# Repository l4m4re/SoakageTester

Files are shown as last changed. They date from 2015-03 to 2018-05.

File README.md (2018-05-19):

# SoakageTester
Hard and software for studying dielectric absorption aka "soakage" in electrolytic capacitors and/or batteries

# Intro

This is a capacitor/battery pulsed charge-discharge cycle tester, as part of a
project to investigate the theory that the well known "capacitor soakage" or
"battery action" effect observed with electrolytic capacitors can be enhanced
using pulsed charging, as demonstrated by John Bedini et al for years. For
more information on the theory, see my article about [The Cole-Hackenberger
(Gray) Power
Supply](http://www.tuks.nl/wiki/index.php/Main/ColeHackenbergerPowerSupply).

# Hardware

The hardware consists of:

1) An adjustable power supply, 0-300V;
2) Pulse charge circuitry, steered by a BeagleBone, using a MOSFET;
3) Current measurement circuitry, using a shunt, some opamps to amplify
the input signal, implement a low pass filter, etc.
4) Voltage measurement circuitry.

Both the current en voltage measurements are done by the BeagleBone using
it's analog inputs and it's ADC. 

Based on [small-scope](https://hackaday.io/project/5881-small-scope) by Marvin Sinister.

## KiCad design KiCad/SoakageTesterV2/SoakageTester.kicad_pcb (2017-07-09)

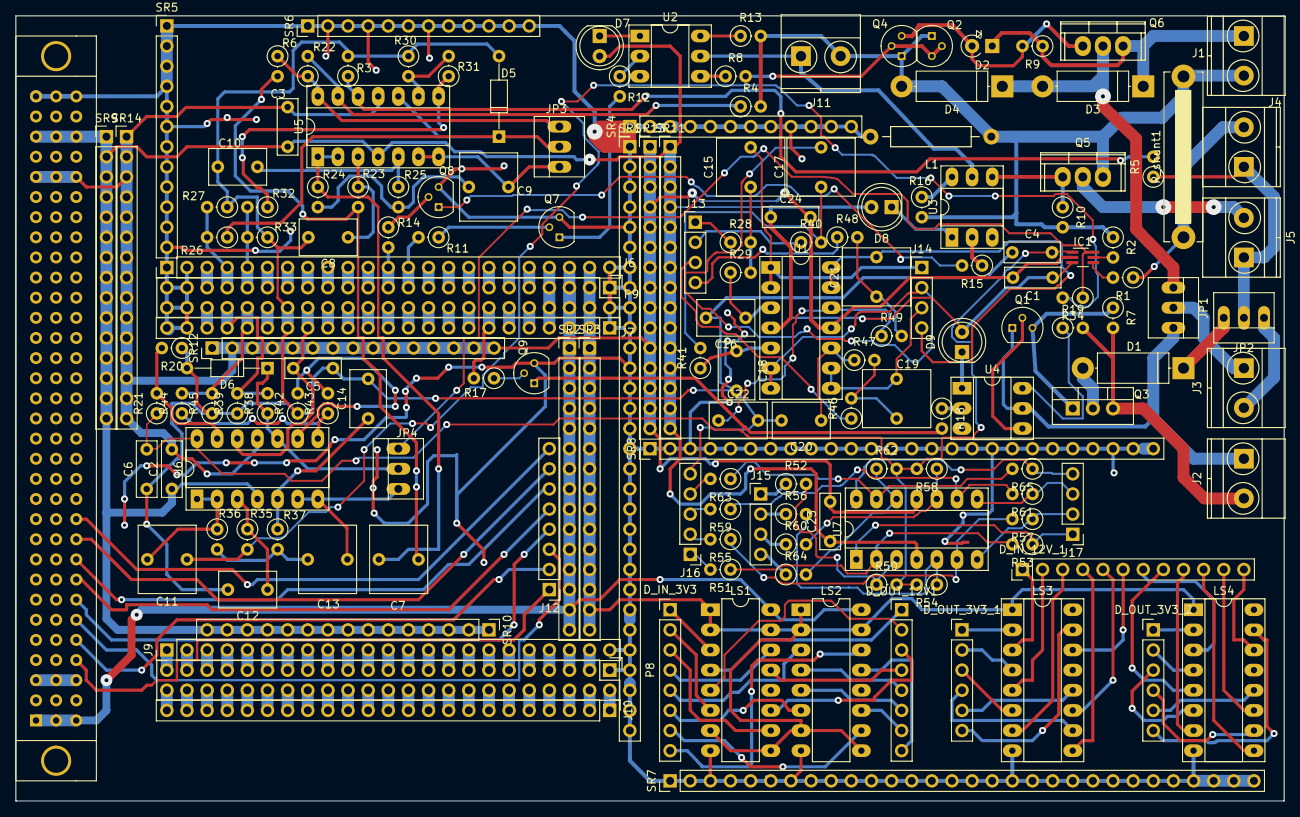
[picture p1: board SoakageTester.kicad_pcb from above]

Board: 2 copper layers, 160.0 x 99.1 mm, 163 parts (0 on the bottom side), 230 nets.

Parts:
C1, C2, C3, C4, C5, C6, C23, C24: 100n; C_Rect_L7.0mm_W2.5mm_P5.00mm
C7, C9, C11, C13, C15, C17, C19, C21: 10n; C_Rect_L7.2mm_W8.5mm_P5.00mm_FKP2_FKP2_MKS2_MKP2
C8, C10, C12, C14, C16, C18, C20, C22: 1n; C_Rect_L7.2mm_W4.5mm_P5.00mm_FKS2_FKP2_MKS2_MKP2
D1, D3, D4: 1N4007; D_5W_P12.70mm_Horizontal
D2: 12V; D_A-405_P2.54mm_Vertical_KathodeUp
D5, D6: 1n4148; D_DO-35_SOD27_P10.16mm_Horizontal
D7, D8, D9: LED; LED_D5.0mm
D_IN_3V3: CONN_01X08; Pin_Header_Straight_1x08_Pitch2.54mm
D_IN_12V_1: CONN_01X12; Pin_Header_Straight_1x12_Pitch2.54mm
D_OUT_3V3_1, D_OUT_3V3_2: CONN_01X06; Pin_Header_Straight_1x06_Pitch2.54mm
D_OUT_12V1: CONN_01X08; Pin_Header_Straight_1x08_Pitch2.54mm
IC1: ina213; SOT-363_SC-70-6_Handsoldering
J1: 30-300V; TerminalBlock_Pheonix_MKDS1.5-2pol
J2: 12V_Bedini; TerminalBlock_Pheonix_MKDS1.5-2pol
J3: Coil; TerminalBlock_Pheonix_MKDS1.5-2pol
J4: Test Cap; TerminalBlock_Pheonix_MKDS1.5-2pol
J5: Load; TerminalBlock_Pheonix_MKDS1.5-2pol
J6, J7, J9, J10: CONN_01X23; Pin_Header_Straight_1x23_Pitch2.54mm
J8: C96ABC; C96ABCMD
J11: 12V Opto; TerminalBlock_Pheonix_MKDS1.5-2pol
J12: CONN_01X08; Pin_Header_Straight_1x08_Pitch2.54mm
J13, J14, J15, J17: CONN_01X04; Pin_Header_Straight_1x04_Pitch2.54mm
J16: CONN_01X05; Pin_Header_Straight_1x05_Pitch2.54mm
JP1, JP2, JP3, JP4: Jumper_NC_Dual; PINHEAD1-3
L1: 10m; Choke_Horizontal_RM15mm
LS1, LS2: CD40109BPW_SOP65P640X120-16N; DIP-16_W7.62mm_LongPads
LS3, LS4: CD74HC4050E_DIP254P762X508-16; DIP-16_W7.62mm_Socket_LongPads
P8, P9: BeagleBone_Black_Header; Socket_BeagleBone_Black
Q1, Q7, Q8, Q9: BC337-40; TO-92_Molded_Narrow
Q2, Q4: MPSA42; TO-92_Molded_Narrow
Q3: BUX85; TO-220_Vertical
Q5: IRFB3307; TO-220
Q6: IXTP10P50P; TO-220
R1, R2: 180k; R_Axial_DIN0207_L6.3mm_D2.5mm_P2.54mm_Vertical
R3, R6, R10, R20: 10k; R_Axial_DIN0207_L6.3mm_D2.5mm_P2.54mm_Vertical
R4, R5, R13, R16, R19, R31, R43: 1M; R_Axial_DIN0207_L6.3mm_D2.5mm_P2.54mm_Vertical
R7, R12, R15, R18, R27, R33, R39, R45: 1k; R_Axial_DIN0207_L6.3mm_D2.5mm_P2.54mm_Vertical
R8: 680; R_Axial_DIN0207_L6.3mm_D2.5mm_P2.54mm_Vertical
R9: 22k; R_Axial_DIN0207_L6.3mm_D2.5mm_P2.54mm_Vertical
R11, R14, R17: 3k3; R_Axial_DIN0207_L6.3mm_D2.5mm_P2.54mm_Vertical
R21: 20k; R_Axial_DIN0207_L6.3mm_D2.5mm_P2.54mm_Vertical
R22, R28, R34, R40, R46, R48: 453; R_Axial_DIN0207_L6.3mm_D2.5mm_P2.54mm_Vertical
R23, R35: 1k78; R_Axial_DIN0207_L6.3mm_D2.5mm_P2.54mm_Vertical
R24, R36: 243; R_Axial_DIN0207_L6.3mm_D2.5mm_P2.54mm_Vertical
R25, R37: 4k32; R_Axial_DIN0207_L6.3mm_D2.5mm_P2.54mm_Vertical
R26, R32, R38, R44: 4k99; R_Axial_DIN0207_L6.3mm_D2.5mm_P2.54mm_Vertical
R29, R41, R47, R49: 1234; R_Axial_DIN0207_L6.3mm_D2.5mm_P2.54mm_Vertical
R30, R42: 40k; R_Axial_DIN0207_L6.3mm_D2.5mm_P2.54mm_Vertical
R50, R51, R52, R53, R54, R55, R56, R57, R58, R59, R60, R61, R62, R63, R64, R65: 3456; R_Axial_DIN0207_L6.3mm_D2.5mm_P2.54mm_Vertical
R_shunt1: 10m; R_Bare_Metal_Element_L21.3mm_W4.8mm_P20.30mm
SR1, SR7: CONN_01X30; Pin_Header_Straight_1x30_Pitch2.54mm
SR2, SR3, SR9, SR10, SR11, SR12, SR13, SR14: CONN_01X15; Pin_Header_Straight_1x15_Pitch2.54mm
SR4, SR5, SR6: CONN_01X12; Pin_Header_Straight_1x12_Pitch2.54mm
SR8: CONN_01X26; Pin_Header_Straight_1x26_Pitch2.54mm
U1, U5, U6, U7: LM2902N; DIP-14_W7.62mm_Socket_LongPads
U2, U3, U4: 4N25; DIP-6_W7.62mm_Socket_LongPads

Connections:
+3V3: J6.22, J7.2, LS1.1, LS1.2, LS1.7, LS1.9, LS1.15, LS2.1, LS2.2, LS2.7, LS2.9, LS2.15, LS3.1, LS4.1, P9.3, P9.4, SR3.1, SR3.2, SR3.3, SR3.4, SR3.5, SR3.6, SR3.7, SR3.8, SR3.9, SR3.10, SR3.11, SR3.12, SR3.13, SR3.14, SR3.15
+5V: J6.21, J7.3, J8.A1, J8.B1, J8.C1, LS1.16, LS2.16, P9.5, P9.6, SR2.1, SR2.2, SR2.3, SR2.4, SR2.5, SR2.6, SR2.7, SR2.8, SR2.9, SR2.10, SR2.11, SR2.12, SR2.13, SR2.14, SR2.15
+12VA: J11.1, U2.5, U3.5
-5V: J8.A3, J8.B3, J8.C3
/Analog Experimental/Amp1/V_in+: J15.1, R52.1
/Analog Experimental/Amp1/V_in-: J16.1, R51.2
/Analog Experimental/Amp1/V_out: J17.1, R53.1, U7.1
/Analog Experimental/Amp2/V_in+: J15.2, R56.1
/Analog Experimental/Amp2/V_in-: J16.2, R55.2
/Analog Experimental/Amp2/V_out: J17.2, R57.1, U7.7
/Analog Experimental/Amp3/V_in+: J15.3, R60.1
/Analog Experimental/Amp3/V_in-: J16.3, R59.2
/Analog Experimental/Amp3/V_out: J17.3, R61.1, U7.8
/Analog Experimental/Amp4/V_in+: J15.4, R64.1
/Analog Experimental/Amp4/V_in-: J16.4, R63.2
/Analog Experimental/Amp4/V_out: J17.4, R65.1, U7.14
/Analog Experimental/Filter1/V_in: J13.1, R28.1
/Analog Experimental/Filter1/V_out: C15.2, J14.1, U1.1, U1.2
/Analog Experimental/Filter2/V_in: J13.2, R40.1
/Analog Experimental/Filter2/V_out: C17.2, J14.2, U1.6, U1.7
/Analog Experimental/Filter3/V_in: J13.3, R46.1
/Analog Experimental/Filter3/V_out: C19.2, J14.3, U1.8, U1.9
/Analog Experimental/Filter4/V_in: J13.4, R48.1
/Analog Experimental/Filter4/V_out: C21.2, J14.4, U1.13, U1.14
/Analog Experimental/V_ref: C4.2, C6.2, IC1.1, R21.1, R50.2, R54.2, R58.2, R62.2, U6.14
/Beagle/AIN0: J6.4, P9.39, R26.2, R27.2
/Beagle/AIN1: J7.20, P9.40, R38.2, R39.2
/Beagle/AIN2: J6.5, P9.37, R32.2, R33.2
/Beagle/AIN3: J7.19, P9.38, R44.2, R45.2
/Beagle/AIN4: J6.7, P9.33
/Beagle/AIN5: J7.18, P9.36
/Beagle/AIN6: J6.6, P9.35
/Beagle/Bedini: J7.7, P9.14, R17.2
/Beagle/C4: J8.C4, J12.1
/Beagle/C5: J8.C5, J12.2
/Beagle/C6: J8.C6, J12.3
/Beagle/C7: J8.C7, J12.4
/Beagle/C8: J8.C8, J12.5
/Beagle/C9: J8.C9, J12.6
/Beagle/C10: J8.C10, J12.7
/Beagle/C11: J8.C11, J12.8
/Beagle/Charge: J6.13, P9.21, R11.2
/Beagle/Discharge: J6.12, P9.23, R14.2
/Beagle/GPIO_7: J7.21, P9.42
/Beagle/GPIO_20: J6.3, P9.41
/Beagle/PWR_BUT: J6.19, P9.9
/Beagle/SYS_RESETN: J7.5, P9.10
/Input Amplifier/IC1_IN_NEG: IC1.5, R2.2
/Input Amplifier/IC1_IN_POS: IC1.4, R1.2
/Input Amplifier/I_sense: J4.2, R1.1, R_shunt1.1
/Input Amplifier/Is_x_5: IC1.6, JP4.3, R34.1
/Input Amplifier/V_cap: J4.1, J5.1, JP2.2, R5.1
/Input Amplifier/V_cap_div_100: JP3.3, R6.1, R22.1, U5.14
/Power Electronics/+300V_PWR: D2.1, D3.1, J1.1, Q6.3, R9.1
/Power Electronics/Bedini+12V: J2.1, JP1.3, Q1.1, U4.5
/Power Electronics/BediniOpto/OUT_Emitter: Q1.2, U4.4
/Power Electronics/Bedini_GND: J2.2, Q3.3, R7.2, R19.2
/Power Electronics/ChargeOpto/OUT_Emitter: R8.1, U2.4
/Power Electronics/DischargeOpto/OUT_Emitter: Q5.1, R10.1, U3.4
/experimental/1A1: D_IN_12V_1.1, LS3.3
/experimental/1A2: D_IN_12V_1.2, LS3.5
/experimental/1A3: D_IN_12V_1.3, LS3.7
/experimental/1A4: D_IN_12V_1.4, LS3.9
/experimental/1A5: D_IN_12V_1.5, LS3.11
/experimental/1A6: D_IN_12V_1.6, LS3.14
/experimental/2A1: D_IN_12V_1.7, LS4.3
/experimental/2A2: D_IN_12V_1.8, LS4.5
/experimental/2A3: D_IN_12V_1.9, LS4.7
/experimental/2A4: D_IN_12V_1.10, LS4.9
/experimental/2A5: D_IN_12V_1.11, LS4.11
/experimental/2A6: D_IN_12V_1.12, LS4.14
/experimental/A1: D_IN_3V3.1, LS1.3
/experimental/A2: D_IN_3V3.5, LS2.3
/experimental/B1: D_IN_3V3.2, LS1.6
/experimental/B2: D_IN_3V3.6, LS2.6
/experimental/C1: D_IN_3V3.3, LS1.10
/experimental/C2: D_IN_3V3.7, LS2.10
/experimental/D1: D_IN_3V3.4, LS1.14
/experimental/D2: D_IN_3V3.8, LS2.14
/experimental/E1: D_OUT_12V1.1, LS1.4
/experimental/E2: D_OUT_12V1.5, LS2.4
/experimental/F1: D_OUT_12V1.2, LS1.5
/experimental/F2: D_OUT_12V1.6, LS2.5
/experimental/G1: D_OUT_12V1.3, LS1.11
/experimental/G2: D_OUT_12V1.7, LS2.11
/experimental/H1: D_OUT_12V1.4, LS1.13
/experimental/H2: D_OUT_12V1.8, LS2.13
GNDA_ADC: C4.1, C5.1, C6.1, C8.2, C10.2, C12.2, C14.2, C16.2, C18.2, C20.2, C22.2, D5.2, D6.2, J7.17, J16.5, P9.34, R3.2, R20.1, R27.1, R30.1, R33.1, R39.1, R42.1, R45.1
GNDD: J6.1, J6.2, J6.23, J7.1, J7.22, J7.23, J8.A32, J8.B32, J8.C32, J9.23, L1.2, LS1.8, LS2.8, LS3.8, LS4.8, P8.1, P9.1, P9.2, P9.43, P9.44, P9.45, P9.46, Q7.3, Q8.3, Q9.3, SR1.1, SR1.2, SR1.3, SR1.4, SR1.5, SR1.6, SR1.7, SR1.8, SR1.9, SR1.10, SR1.11, SR1.12, SR1.13, SR1.14, SR1.15, SR1.16, SR1.17, SR1.18, SR1.19, SR1.20, SR1.21, SR1.22, SR1.23, SR1.24, SR1.25, SR1.26, SR1.27, SR1.28, SR1.29, SR1.30, SR4.1, SR4.2, SR4.3, SR4.4, SR4.5, SR4.6, SR4.7, SR4.8, SR4.9, SR4.10, SR4.11, SR4.12, SR5.1, SR5.2, SR5.3, SR5.4, SR5.5, SR5.6, SR5.7, SR5.8, SR5.9, SR5.10, SR5.11, SR5.12, SR6.1, SR6.2, SR6.3, SR6.4, SR6.5, SR6.6, SR6.7, SR6.8, SR6.9, SR6.10, SR6.11, SR6.12, SR7.1, SR7.2, SR7.3, SR7.4, SR7.5, SR7.6, SR7.7, SR7.8, SR7.9, SR7.10, SR7.11, SR7.12, SR7.13, SR7.14, SR7.15, SR7.16, SR7.17, SR7.18, SR7.19, SR7.20, SR7.21, SR7.22, SR7.23, SR7.24, SR7.25, SR7.26, SR7.27, SR7.28, SR7.29, SR7.30, SR8.1, SR8.2, SR8.3, SR8.4, SR8.5, SR8.6, SR8.7, SR8.8, SR8.9, SR8.10, SR8.11, SR8.12, SR8.13, SR8.14, SR8.15, SR8.16, SR8.17, SR8.18, SR8.19, SR8.20, SR8.21, SR8.22, SR8.23, SR8.24, SR8.25, SR8.26
GNDPWR: D4.2, J1.2, J11.2, L1.1, Q2.1, Q4.1, Q5.3, R2.1, R4.2, R10.2, R13.2, R16.2, R_shunt1.2
unnamed: C7.1, R22.2, R23.2
unnamed: C7.2, R24.1, U5.1, U5.2
unnamed: C8.1, R23.1, U5.3
unnamed: C9.1, R24.2, R25.2
unnamed: C9.2, JP3.1, U5.6, U5.7
unnamed: C10.1, R25.1, U5.5
unnamed: C11.1, R34.2, R35.2
unnamed: C11.2, R36.1, U6.1, U6.2
unnamed: C12.1, R35.1, U6.3
unnamed: C13.1, R36.2, R37.2
unnamed: C13.2, JP4.1, U6.6, U6.7
unnamed: C14.1, R37.1, U6.5
unnamed: C15.1, R28.2, R29.2
unnamed: C16.1, R29.1, U1.3
unnamed: C17.1, R40.2, R41.2
unnamed: C18.1, R41.1, U1.5
unnamed: C19.1, R46.2, R47.2
unnamed: C20.1, R47.1, U1.10
unnamed: C21.1, R48.2, R49.2
unnamed: C22.1, R49.1, U1.12
unnamed: D1.1, JP2.3
unnamed: D1.2, Q3.2
unnamed: D2.2, Q4.3, Q6.1, R9.2
unnamed: D3.2, D4.1, JP1.1, Q6.2
unnamed: D5.1, JP3.2, R26.1, U5.10
unnamed: D6.1, JP4.2, R38.1, U6.10
unnamed: D7.1, U2.1
unnamed: D8.1, U3.1
unnamed: D9.1, U4.1
unnamed: D_OUT_3V3_1.1, LS3.2
unnamed: D_OUT_3V3_1.2, LS3.4
unnamed: D_OUT_3V3_1.3, LS3.6
unnamed: D_OUT_3V3_1.4, LS3.10
unnamed: D_OUT_3V3_1.5, LS3.12
unnamed: D_OUT_3V3_1.6, LS3.15
unnamed: D_OUT_3V3_2.1, LS4.2
unnamed: D_OUT_3V3_2.2, LS4.4
unnamed: D_OUT_3V3_2.3, LS4.6
unnamed: D_OUT_3V3_2.4, LS4.10
unnamed: D_OUT_3V3_2.5, LS4.12
unnamed: D_OUT_3V3_2.6, LS4.15
unnamed: J3.1, JP1.2
unnamed: J3.2, JP2.1
unnamed: J5.2, Q5.2
unnamed: J6.8, P9.31
unnamed: J6.9, P9.29
unnamed: J6.10, P9.27
unnamed: J6.11, P9.25
unnamed: J6.14, P9.19
unnamed: J6.15, P9.17
unnamed: J6.16, P9.15
unnamed: J6.17, P9.13
unnamed: J6.18, P9.11
unnamed: J7.6, P9.12
unnamed: J7.8, P9.16
unnamed: J7.9, P9.18
unnamed: J7.10, P9.20
unnamed: J7.11, P9.22
unnamed: J7.12, P9.24
unnamed: J7.13, P9.26
unnamed: J7.14, P9.28
unnamed: J7.15, P9.30
unnamed: J9.1, P8.45
unnamed: J9.2, P8.43
unnamed: J9.3, P8.41
unnamed: J9.4, P8.39
unnamed: J9.5, P8.37
unnamed: J9.6, P8.35
unnamed: J9.7, P8.33
unnamed: J9.8, P8.31
unnamed: J9.9, P8.29
unnamed: J9.10, P8.27
unnamed: J9.11, P8.25
unnamed: J9.12, P8.23
unnamed: J9.13, P8.21
unnamed: J9.14, P8.19
unnamed: J9.15, P8.17
unnamed: J9.16, P8.15
unnamed: J9.17, P8.13
unnamed: J9.18, P8.11
unnamed: J9.19, P8.9
unnamed: J9.20, P8.7
unnamed: J9.21, P8.5
unnamed: J9.22, P8.3
unnamed: J10.1, P8.2
unnamed: J10.2, P8.4
unnamed: J10.3, P8.6
unnamed: J10.4, P8.8
unnamed: J10.5, P8.10
unnamed: J10.6, P8.12
unnamed: J10.7, P8.14
unnamed: J10.8, P8.16
unnamed: J10.9, P8.18
unnamed: J10.10, P8.20
unnamed: J10.11, P8.22
unnamed: J10.12, P8.24
unnamed: J10.13, P8.26
unnamed: J10.14, P8.28
unnamed: J10.15, P8.30
unnamed: J10.16, P8.32
unnamed: J10.17, P8.34
unnamed: J10.18, P8.36
unnamed: J10.19, P8.38
unnamed: J10.20, P8.40
unnamed: J10.21, P8.42
unnamed: J10.22, P8.44
unnamed: J10.23, P8.46
unnamed: Q1.3, Q3.1, R7.1
unnamed: Q2.2, Q2.3, Q4.2, R8.2
unnamed: Q7.1, R12.2
unnamed: Q7.2, R11.1
unnamed: Q8.1, R15.2
unnamed: Q8.2, R14.1
unnamed: Q9.1, R18.2
unnamed: Q9.2, R17.1
unnamed: R3.1, R5.2, U5.12
unnamed: R4.1, R6.2, U5.13
unnamed: R12.1, U2.2
unnamed: R13.1, U2.6
unnamed: R15.1, U3.2
unnamed: R16.1, U3.6
unnamed: R18.1, U4.2
unnamed: R19.1, U4.6
unnamed: R20.2, R21.2, U6.13
unnamed: R30.2, R31.2, U5.9
unnamed: R31.1, R32.1, U5.8
unnamed: R42.2, R43.2, U6.9
unnamed: R43.1, R44.1, U6.8
unnamed: R50.1, R52.2, U7.3
unnamed: R51.1, R53.2, U7.2
unnamed: R54.1, R56.2, U7.5
unnamed: R55.1, R57.2, U7.6
unnamed: R58.1, R60.2, U7.10
unnamed: R59.1, R61.2, U7.9
unnamed: R62.1, R64.2, U7.12
unnamed: R63.1, R65.2, U7.13
OPAMP_Vdd: C1.2, C2.2, C3.2, C23.2, C24.2, IC1.2, J8.A28, J8.B28, J8.C28, SR12.1, SR12.2, SR12.3, SR12.4, SR12.5, SR12.6, SR12.7, SR12.8, SR12.9, SR12.10, SR12.11, SR12.12, SR12.13, SR12.14, SR12.15, SR13.1, SR13.2, SR13.3, SR13.4, SR13.5, SR13.6, SR13.7, SR13.8, SR13.9, SR13.10, SR13.11, SR13.12, SR13.13, SR13.14, SR13.15, SR14.1, SR14.2, SR14.3, SR14.4, SR14.5, SR14.6, SR14.7, SR14.8, SR14.9, SR14.10, SR14.11, SR14.12, SR14.13, SR14.14, SR14.15, U1.11, U5.11, U6.11, U7.11
OPAMP_Vss: C1.1, C2.1, C3.1, C23.1, C24.1, D7.2, D8.2, D9.2, IC1.3, J8.A30, J8.B30, J8.C30, SR9.1, SR9.2, SR9.3, SR9.4, SR9.5, SR9.6, SR9.7, SR9.8, SR9.9, SR9.10, SR9.11, SR9.12, SR9.13, SR9.14, SR9.15, SR10.1, SR10.2, SR10.3, SR10.4, SR10.5, SR10.6, SR10.7, SR10.8, SR10.9, SR10.10, SR10.11, SR10.12, SR10.13, SR10.14, SR10.15, SR11.1, SR11.2, SR11.3, SR11.4, SR11.5, SR11.6, SR11.7, SR11.8, SR11.9, SR11.10, SR11.11, SR11.12, SR11.13, SR11.14, SR11.15, U1.4, U5.4, U6.4, U7.4
SYS_5V: J6.20, J7.4, P9.7, P9.8
VDD_ADC: C5.2, J7.16, P9.32, U6.12

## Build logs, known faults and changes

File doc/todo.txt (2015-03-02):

Problems:

1) Offset current-measurement drifts. 
  - Use zener diode + 2 equal transistors
  - Continuously re-calibrate

	Measurements:
	09/05  9:55  2.52V / -0.11A 

2) Resolution too low at low currents. 
  - Change amplification of last opamp section
  - Add second opamp section for low currents and
    switch between 2 resolutions, f.e. at 4.5 A.

3) Low-pass filter may add too much error.
  - increase sampling freq & filter edge freq
  - decrease order of filter.

TODO:

1) Higher voltages with variac

2) User interface with python script

3) Nelder Mead optimizer

Simulate with 6 kHz, 50% duty and see max amp.
-> no success at 6 kHz. Max current about 40 Amps.

ORDER:

- transistors 
  - small signal NPN+PNP
  - high voltage NPN like BF393

- 2.5V zeners / 0.9V zener / ref voltage.

- SMD IC's Kimo's remote

- PCB's

- Litze / tin

- screwing connectors

- some pots, like 10-turns 

- OPAMPS
  - TL074/084
  - LM324

- Long Arduino/Beagle connectors/headers

- External ADC or Arduino Zero or Due (EUR 43) (12-bit ADC)

----------------------------------------------------------------------

Arduino Due also has 12-bit ADC.

Arduino comparison and ADC explanation and calibration:
http://www.djerickson.com/arduino/

Due:
Flash     : 512K
RAM       : 96K
ADC inputs: 16 x 12 bits, 1MHz

http://frenki.net/2013/10/fast-analogread-with-arduino-due/

"With this improvement conversion time dropped to 1.79uS."

That would be 558 kHz.

Well enough for 3 channels at 128 or 2 at 256 kHz. :)

"But then I found great piece of code from arduino forum use
"stimmer" which ignores analogRead by using more direc
approach: http://goo.gl/Bn8Z4P
With this solution single conversion takes only 1uS
And now we have a cheap 1MSa/s oscilloscope. ;)"

This is in free-running mode, though. 

That would mean: 1 MHz max, or 500 kHz for 2 channels or
333 kHz for 3 channes.
Well enough for 3 channels at 128 or 256 kHz. :)

Comments:

"To get 1 msps you need to set prescaller at 21 MHz.  Right, it's
"overclocking" , as data sheet says 20 MHz is max Check it out, there is
a code: http://coolarduino.blogspot.ca/2015_06_01_archive.html"

Available via archive.org:

http://web.archive.org/web/20150814074247/http://coolarduino.blogspot.ca/2015/07/fast-sampling-with-arduino-due.html

Further comments:

-:-

Anatoly Kuzmenko : Hi! Thanks for the tip! I've checked out the Atmel
SAM3X8E datasheet
(http://www.atmel.com/.../Atmel-11057-32-bit-Cortex-M3...). And I found
that the ADCClock=MCK/((PRESCAL+1)*2) in page 1334. Also, in page 1403,
it shows that max. ADC Clock is 22MHZ , and the Conversion
time(tCONV)=20*ADC Clock Period(tCP_ADC) . That means, theoretically,
Due's ADC sampling rate= MCK/40N, where MCK=84MHZ and N=2 to 42. The
maximum sampling rate would be 84MHZ/(40*2)=1.05MHZ ! It's better than
expected, and It's not overclocking!

Am I right?
Like · Reply · Jul 10, 2015 9:56am
Anatoly Kuzmenko ·
Centre Pauline Julien

Chi-hao Li : Wrong. I'm sure, atmel made another mistake, "typo" this
time. I have doc dated 2012, that says 20 MHz:

https://drive.google.com/.../0Bw4tXXvyWtFVdmRsLVh.../view...

Here is confirmation:

http://asf.atmel.com/docs/latest/sam3x/html/adc_8h.html

This explain, why you can't run ADC at 1 MHZ if you set : adc_init(ADC,
SystemCoreClock, ADC_FREQ_MAX, ADC_STARTUP_FAST);

It has to be:

adc_init(ADC, SystemCoreClock, 21000000UL, ADC_STARTUP_FAST);

http://coolarduino.blogspot.ca/.../fast-sampling-with...

-:-

Continue at:

https://gist.github.com/pklaus/5921022

In-circuit debugging:

http://forum.arduino.cc/index.php?topic=134907.15

"For those interested in debugging Arduino Due and saving some money, I
recommend to use an Atmel ICE that costs around $25 or a SWD CMSIS-DAP
($20) like the one from adafruit and shown in the following picture,
instead of pay over $100 for a SAM-ICE. Of course, the mentioned cheap
options have limited features but at least let you to perform debugging
functions like stepping, breakpoints, watch points, and firmware
downloads."

The Adafruit one can be ordered in the UK for about EUR 40, incl p&p:
http://www.ebay.nl/itm/Adafruit-IBDAP-CMSIS-DAP-JTAG-SWD-Debug-Adapter-Kit-ADA2764-/151984771454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

Other boards:

BeagleBone

https://www.conrad.nl/nl/seeed-studio-102010027-beaglebone-green-1389300.html

EUR 50.

EUR 36 at Mouser:
http://nl.mouser.com/ProductDetail/Seeed-Studio/102010027/?qs=Hlcjo%2fO3pQ5AxSET1oW%252b%252bg%3d%3d

BB-BBLK-000 Rev C BeagleBone Black Mini-PC Rev C (element14 editie)
EUR 65
EUR 52 at Mouser

http://www.seeedstudio.com/wiki/BeagleBone_Green#Analog_Inputs

This is a single 12-bit analog-to-digital converter with 8 channels,
7 of which are made available on the headers.  

http://beaglebone.cameon.net/home/reading-the-analog-inputs-adc

There are 7 analog inputs on the BeagleBone.

ADC properties:
 - 12 bits (Output values in the range 0-4095)
 - 125ns sample time -> 8 MHz :)
 - 0-1.8V range (do not exceed!)
 - 2 uA current flows into the ADC pin in this range
 - If using a voltage divider, the lower leg (the one connected to ground) should be <= 1k Ohm
 - Since we are measuring millivolts, resistors with 0.1% error tolerance should be used in a voltage divider.
 - There is a 1.8V reference voltage VDD_ADC at Port 9 Pin 32.
 - There is a GNDA_ADC that should be grounded on Port9 Pin 34.

Comment:

Thanks for infos, but I think that ADC sub-system sample time is about
15 ADC clock cycles (at 24MHz (typ) it will be 41.6nSec per cycle)
results into about 625nSec .  See Technical Reference for AM335x page
1152 (REV.F) .

That would mean: 1.6 MHz max, or 800 kHz for 2 channels c.q. 533 kHz for
3 channes.  Well enough for 3 channels at 128 or 256 kHz. :)

Driver:

https://github.com/pgmmpk/beaglebone_pru_adc (refers to above comment)

The libpruio library appears to be a better driver:

http://beagleboard.org/project/libpruio/
http://users.freebasic-portal.de/tjf/Projekte/libpruio/doc/html/
https://www.freebasic-portal.de/downloads/fb-on-arm/libpruio-325.html

This uses the Programmable Realtime Unit SubSystem (= PRUSS or just PRU)
co-processors for accessing the hardware, so the CPU does not need to
bother handling the I/O. 

There is a small bug in the library, which limits the sampling rate,
which can be patched manually, as stated by the author:

https://groups.google.com/forum/#!msg/beagleboard/CN5qKSmPIbc/2UdstwjNhHMJ

-:-
Regarding the ADC speed I made some further testing and it seems that I
mis-interpreted the TRM. The ADC subsystem can sample at least at 200
kS/s. This speed also works for multiple channels. Find an example of
our channels at 44.1 kHz in this post. An overall sampling rate of 200
kHz was also possible (four channels).

So the limiting in the current libpruio-0.2 is too much on the safe
site. If you don't want to wait for the next version, you can adapt the
code by yourself (FreeBASIC compiler required). Replace in file
pruio_adc.bas in function PruIo.configure(...) the lines

      d *= (Conf->ADC_CLKDIV + 1) * 417 '417 ≈ 1000000 / 2400 (= 1 GHz / 2.4 MHz)
      d += 30 '                             PRU cycles for restart [GHz]
      IF Tmr <= d THEN     .Errr = @"sample rate too big" : RETURN .Errr

by the following code

      d = (d * (Conf->ADC_CLKDIV + 1) * 1000) \ 24
      IF Tmr <= d ORELSE Tmr < 5000 THEN _
                           .Errr = @"sample rate too big" : RETURN .Errr

You may play a bit with the absolute value 5000. On my BBB the timing is
OK up to a frequency of 240 kHz (4165). But this may vary from board to
board.
-:-

Beagle Connectors:

https://www.adafruit.com/category/75

2x23 Male Headers for BeagleBone Black - Two Pack!

These simple 2x23 male headers are a great addition to your Beagle Bone
Black, plugging right into each set of side-sockets.  Each pack comes
with two headers so you can connect prototype PCBs or capes on. Each
header is 0.1"x 0.1" grid spacing

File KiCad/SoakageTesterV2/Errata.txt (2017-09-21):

Known errors/issues.
====================

* The Bedini circuit around Q3 is incorrect. Only the spike recovery circuit
 (D1) is included, but not the coil activation connection to the collector of
Q3. 

* C7 has been placed close to U6 instead of close to U5. This has led to
  unnecesary long connections.

* The labels for R6 and R22 are exchanged c.q. at the wrong place.

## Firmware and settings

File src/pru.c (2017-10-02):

/////////////////////////////////////////////////////////////////////
// Original source: https://github.com/rvega/bbb-pru

/////////////////////////////////////////////////////////////////////
// UTIL
//
#define HWREG(x) (*((volatile unsigned int *)(x)))
#define min(a,b) (a<b ? a : b)

/////////////////////////////////////////////////////////////////////
// GLOBALS
//

void init_adc();

volatile register unsigned int __R31;
volatile unsigned int* shared_ram;
volatile unsigned int* shared_vars;
//volatile unsigned int* shared_ram_end;
volatile unsigned int* buffer;


/* Shared RAM size is 12 kB. Since the actual data is 16 bits and a 32 bits
 * buffer was used, this is a waste of memory space. Further, quite some
 * blocks were missed every now and then, so we opt for a ring buffer as big
 * as possible and generate interrupts every x amount of samples.
 */



#define INTERRUPT_FREQ  128
#define VARS_OFFSET      0x2F00
#define MAX_BUF_IDX     (0x2E00/4)

int main(int argc, const char *argv[])
{
    // Init globals
    shared_ram     = (volatile unsigned int *)0x10000;
//    shared_ram_end = (volatile unsigned int *)0x12EFF;
    shared_vars    = (volatile unsigned int *)0x12F00;
    buffer = &(shared_ram[0]); 
    
    // Locals:
    unsigned int buf_idx     = 0;
    unsigned int interrupt_count  = 0; // Enables host to check for missed interrupts.

    init_adc();

    while(1)
    {
        // Read samples from fifo0 and fifo1, put them in a buffer and when
        // block size is reached, send IRQ to ARM host.  
        // Uses FIFO0COUNT, FIFO0DATA, FIFO1COUNT, FIFO1DATA registers.
        //
        // Since we only use two channels and a separate fifo for each channel,
        // the data comes in in order and we need only one set of buffers. There
        // are two buffers, so the the host processor can read from one buffer
        // while we fill the other one.

        __R31 = 0;

        // fifo0_count = HWREG(0x44e0d0e4);
        // fifo1_count = HWREG(0x44e0d0f0); 

        if( HWREG(0x44e0d0e4) && HWREG(0x44e0d0f0) )
        {
            // FIFO 0
            buffer[buf_idx++] = ( HWREG(0x44e0d100) & 0x0FFF ) << 16 | 
                                  HWREG(0x44e0d200) & 0x0FFF;

            if( buf_idx >= MAX_BUF_IDX )
            {
                buf_idx = 0;
            }
        }

        if(buf_idx % INTERRUPT_FREQ == 0)
        {
            // put number of available samples (block size) in position 0,
            // address of buffer in position 1 and IRQ
            shared_vars[0] = VARS_OFFSET;
            shared_vars[1] = buf_idx;
            shared_vars[2] = interrupt_count++;
            shared_vars[3] = MAX_BUF_IDX;
/*
            fifo0_count = HWREG(0x44e0d0e4); 
            fifo1_count = HWREG(0x44e0d0f0);
            shared_ram[3] = fifo0_count;
            shared_ram[4] = fifo1_count;
            shared_ram[5] = which_buffer;
*/
            __R31 = 35;
        }
    }
}

void init_adc()
{
    // Enable OCP so we can access the whole memory map for the
    // device from the PRU. Clear bit 4 of SYSCFG register
    HWREG(0x26004) &= 0xFFFFFFEF;

    // Enable clock for adc module. CM_WKUP_ADC_TSK_CLKCTL register
    HWREG(0x44e004bc) = 0x02;

    // Disable ADC module temporarily. ADC_CTRL register
    HWREG(0x44e0d040) &= ~(0x01);

    // To calculate sample rate:
    // fs = 24MHz / (CLK_DIV*2*Channels*(OpenDly+Average*(14+SampleDly)))
    // We want as fast as possible.
    unsigned int clock_divider = 1;
    unsigned int open_delay    = 0;
    unsigned int sample_delay  = 0;
    unsigned int average       = 0; // can be 0 (no average), 1 (2 samples), 
                                    // 2 (4 samples),  3 (8 samples) 
                                    // or 4 (16 samples)

    // Set clock divider (set register to desired value minus one). 
    // ADC_CLKDIV register
    HWREG(0x44e0d04c) = clock_divider - 1;

    // Set values range from 0 to FFF. ADCRANGE register
    HWREG(0x44e0d048) = (0xfff << 16) & (0x000);

    // Disable all steps. STEPENABLE register
    HWREG(0x44e0d054) &= ~(0xff);

    // Unlock step config register. ACD_CTRL register
    HWREG(0x44e0d040) |= (0x01 << 2);

    // Set config for step 1. sw mode, continuous mode, 
    // use fifo0, use channel 2. STEPCONFIG1 register
    HWREG(0x44e0d064) = 0x0000 | (0x0<<26) | (0x02<<19) | (0x00<<15) | (average<<2) | (0x01);

    // Set delays for step 1. STEPDELAY1 register
    HWREG(0x44e0d068) = 0x0000 | (sample_delay)<<24 | open_delay;

    // Set config for step 2. sw mode, continuous mode, 
    // use fifo0, use channel 1. STEPCONFIG2 register
    /* HWREG(0x44e0d06c) = 0x0000 | (0x0<<26) | (0x01<<19) | (0x01<<15) | (average<<2) | (0x01); */
    //
    // FiFo control bit: 26
    // use fifo0, use channel 2. STEPCONFIG2 register
    /* HWREG(0x44e0d06c) = 0x0000 | (0x0<<26) | (0x02<<19) | (0x02<<15) | (average<<2) | (0x01); */
    // use fifo1, use channel 1. STEPCONFIG2 register
    HWREG(0x44e0d06c) = 0x0000 | (0x1<<26) | (0x01<<19) | (0x02<<15) | (average<<2) | (0x01); 

    // Set delays for step 2. STEPDELAY2 register
    HWREG(0x44e0d070) = 0x0000 | (sample_delay)<<24 | open_delay;

    // Set config for step 3. sw mode, continuous mode, 
    // use fifo0, use channel 2. STEPCONFIG3 register
    /* HWREG(0x44e0d074) = 0x0000 | (0x0<<26) | (0x02<<19) | (0x02<<15) | (average<<2) | (0x01); */

    // Set delays for step 3. STEPDELAY3 register
    /* HWREG(0x44e0d078) = 0x0000 | ((sample_delay)<<24) | open_delay; */

    // Set config for step 4. sw mode, continuous mode, 
    // use fifo1, use channel 3. STEPCONFIG4 register
    /* HWREG(0x44e0d07c) = 0x0000 | (0x0<<26) | (0x03<<19) | (0x03<<15) | (average<<2) | (0x01); */

    // Set delays for step 4. STEPDELAY4 register
    /* HWREG(0x44e0d080) = 0x0000 | ((sample_delay)<<24) | open_delay; */


    // Set config for step 5. sw mode, continuous mode, 
    // use fifo1, use channel 4. STEPCONFIG5 register
    /* HWREG(0x44e0d084) = 0x0000  | (0x0<<26) | (0x04<<19) | (0x04<<15) | (average<<2) | (0x01); */

    // Set delays for step 5. STEPDELAY5 register
    /* HWREG(0x44e0d088) = 0x0000 | ((sample_delay)<<24) | open_delay; */

    // Set config for step 6. sw mode, continuous mode, 
    // use fifo1, use channel 5. STEPCONFIG6 register
    /* HWREG(0x44e0d08c) = 0x0000 | (0x0<<26) | (0x05<<19) | (0x05<<15) | (average<<2) | (0x01); */

    // Set delays for step 6. STEPDELAY6 register
    /* HWREG(0x44e0d090) = 0x0000 | ((sample_delay)<<24) | open_delay; */

    /* // Set config for step 7. Average 16, sw mode, continuous mode,  */
    /* // use fifo0, use channel 6. STEPCONFIG7 register */
    /* HWREG(0x44e0d094) |= ((0x0<<26) | (0x06<<19) | (0x06<<15) | (0x04<<2) | (0x01)); */

    /* // Set delays for step 7. STEPDELAY7 register */
    /* HWREG(0x44e0d098) = 0x0000 | ((sample_delay)<<24) | open_delay; */

    // Lock step config register. ACD_CTRL register
    HWREG(0x44e0d040) &= ~(0x01 << 2);

    // Clear FIFO0 by reading from it. FIFO0COUNT, FIFO0DATA registers
    unsigned int count = HWREG(0x44e0d0e4);
    unsigned int data, i;
    for(i=0; i<count; i++)
    {
        data = HWREG(0x44e0d100);
    }

    // Clear FIFO1 by reading from it. FIFO1COUNT, FIFO1DATA registers
    count = HWREG(0x44e0d0f0);
    for (i=0; i<count; i++)
    {
        data = HWREG(0x44e0d200);
    }
    shared_ram[500] = data; // just to remove unused value compiler warning;

    // Enable tag channel id. ADC_CTRL register
    HWREG(0x44e0d040) |= 0x02;

    // Enable steps 1-4. STEPENABLE register
    /* HWREG(0x44e0d054) = 0x1e; */
    // Enable steps 1-6. STEPENABLE register
    /* HWREG(0x44e0d054) = 0x7e; */
    // Enable steps 1-3. STEPENABLE register
    /* HWREG(0x44e0d054) = 0xe; */
    // Enable steps 1-2. STEPENABLE register
    HWREG(0x44e0d054) = 0x6; 
    // Enable steps 1. STEPENABLE register
    /* HWREG(0x44e0d054) = 0x2; */
    // Enable all steps. STEPENABLE register
    /* HWREG(0x44e0d054) |= 0xfe; */

    // Enable Module (start sampling). ADC_CTRL register
    HWREG(0x44e0d040) |= 0x01;
}

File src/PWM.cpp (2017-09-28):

/*
 * PWM.cpp  Created on: 29 Apr 2014
 * Copyright (c) 2014 Derek Molloy (www.derekmolloy.ie)
 * Made available for the book "Exploring BeagleBone" 
 * See: www.exploringbeaglebone.com
 * Licensed under the EUPL V.1.1
 *
 * This Software is provided to You under the terms of the European 
 * Union Public License (the "EUPL") version 1.1 as published by the 
 * European Union. Any use of this Software, other than as authorized 
 * under this License is strictly prohibited (to the extent such use 
 * is covered by a right of the copyright holder of this Software).
 * 
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
 * For more details, see http://www.derekmolloy.ie/
 */

#include "PWM.h"
#include "util.h"
#include <cstdlib>

namespace exploringBB {

PWM::PWM(string pinName) {
	this->name = pinName;
	this->path = PWM_PATH + this->name + "/";
	this->analogFrequency = 100000;
	this->analogMax = 3.3;
}

int PWM::setPeriod(unsigned int period_ns){
	return write(this->path, PWM_PERIOD, period_ns);
}

unsigned int PWM::getPeriod(){
	return atoi(read(this->path, PWM_PERIOD).c_str());
}

float PWM::period_nsToFrequency(unsigned int period_ns){
	float period_s = (float)period_ns/1000000000;
	return 1.0f/period_s;
}

unsigned int PWM::frequencyToPeriod_ns(float frequency_hz){
	float period_s = 1.0f/frequency_hz;
	return (unsigned int)(period_s*1000000000);
}

int PWM::setFrequency(float frequency_hz){
	return this->setPeriod(this->frequencyToPeriod_ns(frequency_hz));
}

float PWM::getFrequency(){
	return this->period_nsToFrequency(this->getPeriod());
}

int PWM::setDutyCycle(unsigned int duty_ns){
	return write(this->path, PWM_DUTY, duty_ns);
}

int PWM::setDutyPerc(float percentage){
	if ((percentage>100.0f)||(percentage<0.0f)) return -1;
	unsigned int period_ns = this->getPeriod();
	float duty_ns = period_ns * (percentage/100.0f);
	this->setDutyCycle((unsigned int) duty_ns );
	return 0;
}

unsigned int PWM::getDutyCycle(){
	return atoi(read(this->path, PWM_DUTY).c_str());
}

float PWM::getDutyCyclePercent(){
	unsigned int period_ns = this->getPeriod();
	unsigned int duty_ns = this->getDutyCycle();
	return 100.0f * (float)duty_ns/(float)period_ns;
}

int PWM::setPolarity(PWM::POLARITY polarity){
	return write(this->path, PWM_POLARITY, polarity);
}

void PWM::invertPolarity(){
	if (this->getPolarity()==PWM::ACTIVE_LOW) this->setPolarity(PWM::ACTIVE_HIGH);
	else this->setPolarity(PWM::ACTIVE_LOW);
}

PWM::POLARITY PWM::getPolarity(){
	if (atoi(read(this->path, PWM_POLARITY).c_str())==0) return PWM::ACTIVE_LOW;
	else return PWM::ACTIVE_HIGH;
}

int PWM::calibrateAnalogMax(float analogMax){ //must be between 3.2 and 3.4
	if((analogMax<3.2f) || (analogMax>3.4f)) return -1;
	else this->analogMax = analogMax;
	return 0;
}

int PWM::analogWrite(float voltage){
	if ((voltage<0.0f)||(voltage>3.3f)) return -1;
	this->setFrequency(this->analogFrequency);
	this->setPolarity(PWM::ACTIVE_LOW);
	this->setDutyPerc((100.0f*voltage)/this->analogMax);
	return this->run();
}

int PWM::run(){
	return write(this->path, PWM_RUN, 1);
}

bool PWM::isRunning(){
	string running = read(this->path, PWM_RUN);
	return (running=="1");
}

int PWM::stop(){
	return write(this->path, PWM_RUN, 0);
}

PWM::~PWM(){
//	write(this->path, PWM_RUN, 0);
	write(this->path, PWM_DUTY, 0);
}


} /* namespace exploringBB */

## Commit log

2015-03-02 Added (source) files from old Arduino project.
2017-07-09 Check-in of PCB files.
    [AnalogExperimental.sch, Beagle.sch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]
2017-09-11 Reverted workaround for perceived GPIO interference with sampler.
    [SoakTest.cpp]
2017-09-18 Copied Kicad schematic to version 2.
    [AnalogExperimental.sch, Beagle.sch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]
2017-09-21 Included digital BiQuad low pass filter.
2017-09-22 Clean up and replace libpruio with dedicated pru program.
    [SoakTest.cpp]
2017-09-22 Implemented 200 kHz low pass, 8th order Butterworth filter.
2017-09-28 Changed to Bedini charge mode
2017-09-30 Change to Bedini mode. Keep samling thread alive after error.
    [SoakTest.cpp]
2017-10-02 We were missing samples. Changed to ring buffer and RT priority thread.
    [SoakTest.cpp, pru.c]

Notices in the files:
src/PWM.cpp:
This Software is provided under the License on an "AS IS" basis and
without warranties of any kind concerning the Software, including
